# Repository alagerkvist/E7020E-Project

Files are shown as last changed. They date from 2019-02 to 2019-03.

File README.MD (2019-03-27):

# Embbeded Audio Effects

E7020E Embedded System Design is a course giving at Lulea University of Technology. [Link to course syllabus](https://www.ltu.se/edu/course/E70/E7020E/E7020E-Design-av-inbyggda-system-1.67927?kursView=kursplan&l=en)

The purpose of this course is to get a understanding of embedded system and applying that knowledge into designing your own system. Our group did a system that can manipulate audio (adding effects). Where giving an audio input, add some effects and then output it on a speaker.

## Getting Started

* Start by installing Rust for embedded system, follow [this](https://rust-embedded.github.io/book/intro/install.html) guide. 
* Install OpenOCD (version 0.10.0)
* Install arm-none-eabi-gdb (version 8.2.1)
* We are using as of 2019-03-27: rustc 1.34.0-nightly (8a57831a4 2019-02-02)

### Building software
* Clone the repo ``` git clone https://github.com/alagerkvist/E7020E-Project.git ```
* If you would like to use the latest main program run ``` cargo build --release ```
* For examples, run ``` cargo build --example NAME_OF_RS_FILE (codec) ```

## Deployment

* Create FIFO file ``` mkfifo /tmp/itm.log ```
* Start your ITM trace ``` itmdump -f /tmp/itm.log -F ```
* Start OpenOCD ``` openocd -f openocd.cfg ```
* Start gdb ``` arm-none-eabi-gdb target/thumbv7em-none-eabinhf/debug/examples/NAME_OF_RS_FILE -x openocd.gdb ```

## Authors

* **Christoffer Forsberg** - *PCB design*
* **Anders Lagerkvist** - *Programming*
* **Gustav Larsson** - *Programming* 

## Grades
**3**
* Control lamp with PWM signal through UART/potentiometer/button

* **Christoffer Forsberg** - *PWM signal*
* **Anders Lagerkvist** - *ADC for potentiometer*
* **Gustav Larsson** - *Button and UART*

**4**
* Store input siganl in RAM with the help of a button
* Get a sinus wave to output to the codec
* Do an echo with the "signal"
* Show settings on LCD
* Implement I2S/(I2C/SPI) for audio codec

* **Christoffer Forsberg** - *Signal processing, store audio input to RAM with button*
* **Anders Lagerkvist** - *LCD, I2S sine wave output to codec*
* **Gustav Larsson** - *LCD I2C/SPI*

**5**
* Overlay two signals as output
* Integrate different impulse for signal proccessing
* Use an USB as storage

* **Christoffer Forsberg** - *Real time signal processing*
* **Anders Lagerkvist** - *USB implementation*
* **Gustav Larsson** - *Real time signal processing*

## Implemented features

* PWM/LED
* Button
* LCD
* Codec (ish)
* ADC

## Known issues and limitation

* MCUs adc can only read from one potentiometer
* LCD screen has no library yet, so it's a pain in the a** to write to it
* As of now, the codec is inconsistent when writing to it, possible reason to this can be impedance mismatch or wrongfully clock generation 
* PCB layout for 5V to 3.3V regulator is not right implemented
* Footprint for mini-usb type B is placed wrong, should be the other way around (no possibility to mount it on the PCB as of now)
* Codec is in master mode, and should be in slave mode (can be fixed with a pull down resistor instead of a pull up resistor)
* Layout for the potentiometer is too close, needs to seperate more
* Footprint for RCA connector needs to be bigger in their NPTH hole 

## Future work

* Implement ADC so it can be read from three potentiometers
* Library for LCD
* Successfully send data to codec
* Store data from codec into ram
* Sound processing (filter or convolution implementation)
* Store/read data on USB 

## Acknowledgments
PhD Student Cristina Paniagua [Link to profile](https://www.ltu.se/staff/c/cripan-1.167417?l=en)

Professor Per Lindgren [Link to profile](https://www.ltu.se/staff/p/pln-1.11258?l=en)

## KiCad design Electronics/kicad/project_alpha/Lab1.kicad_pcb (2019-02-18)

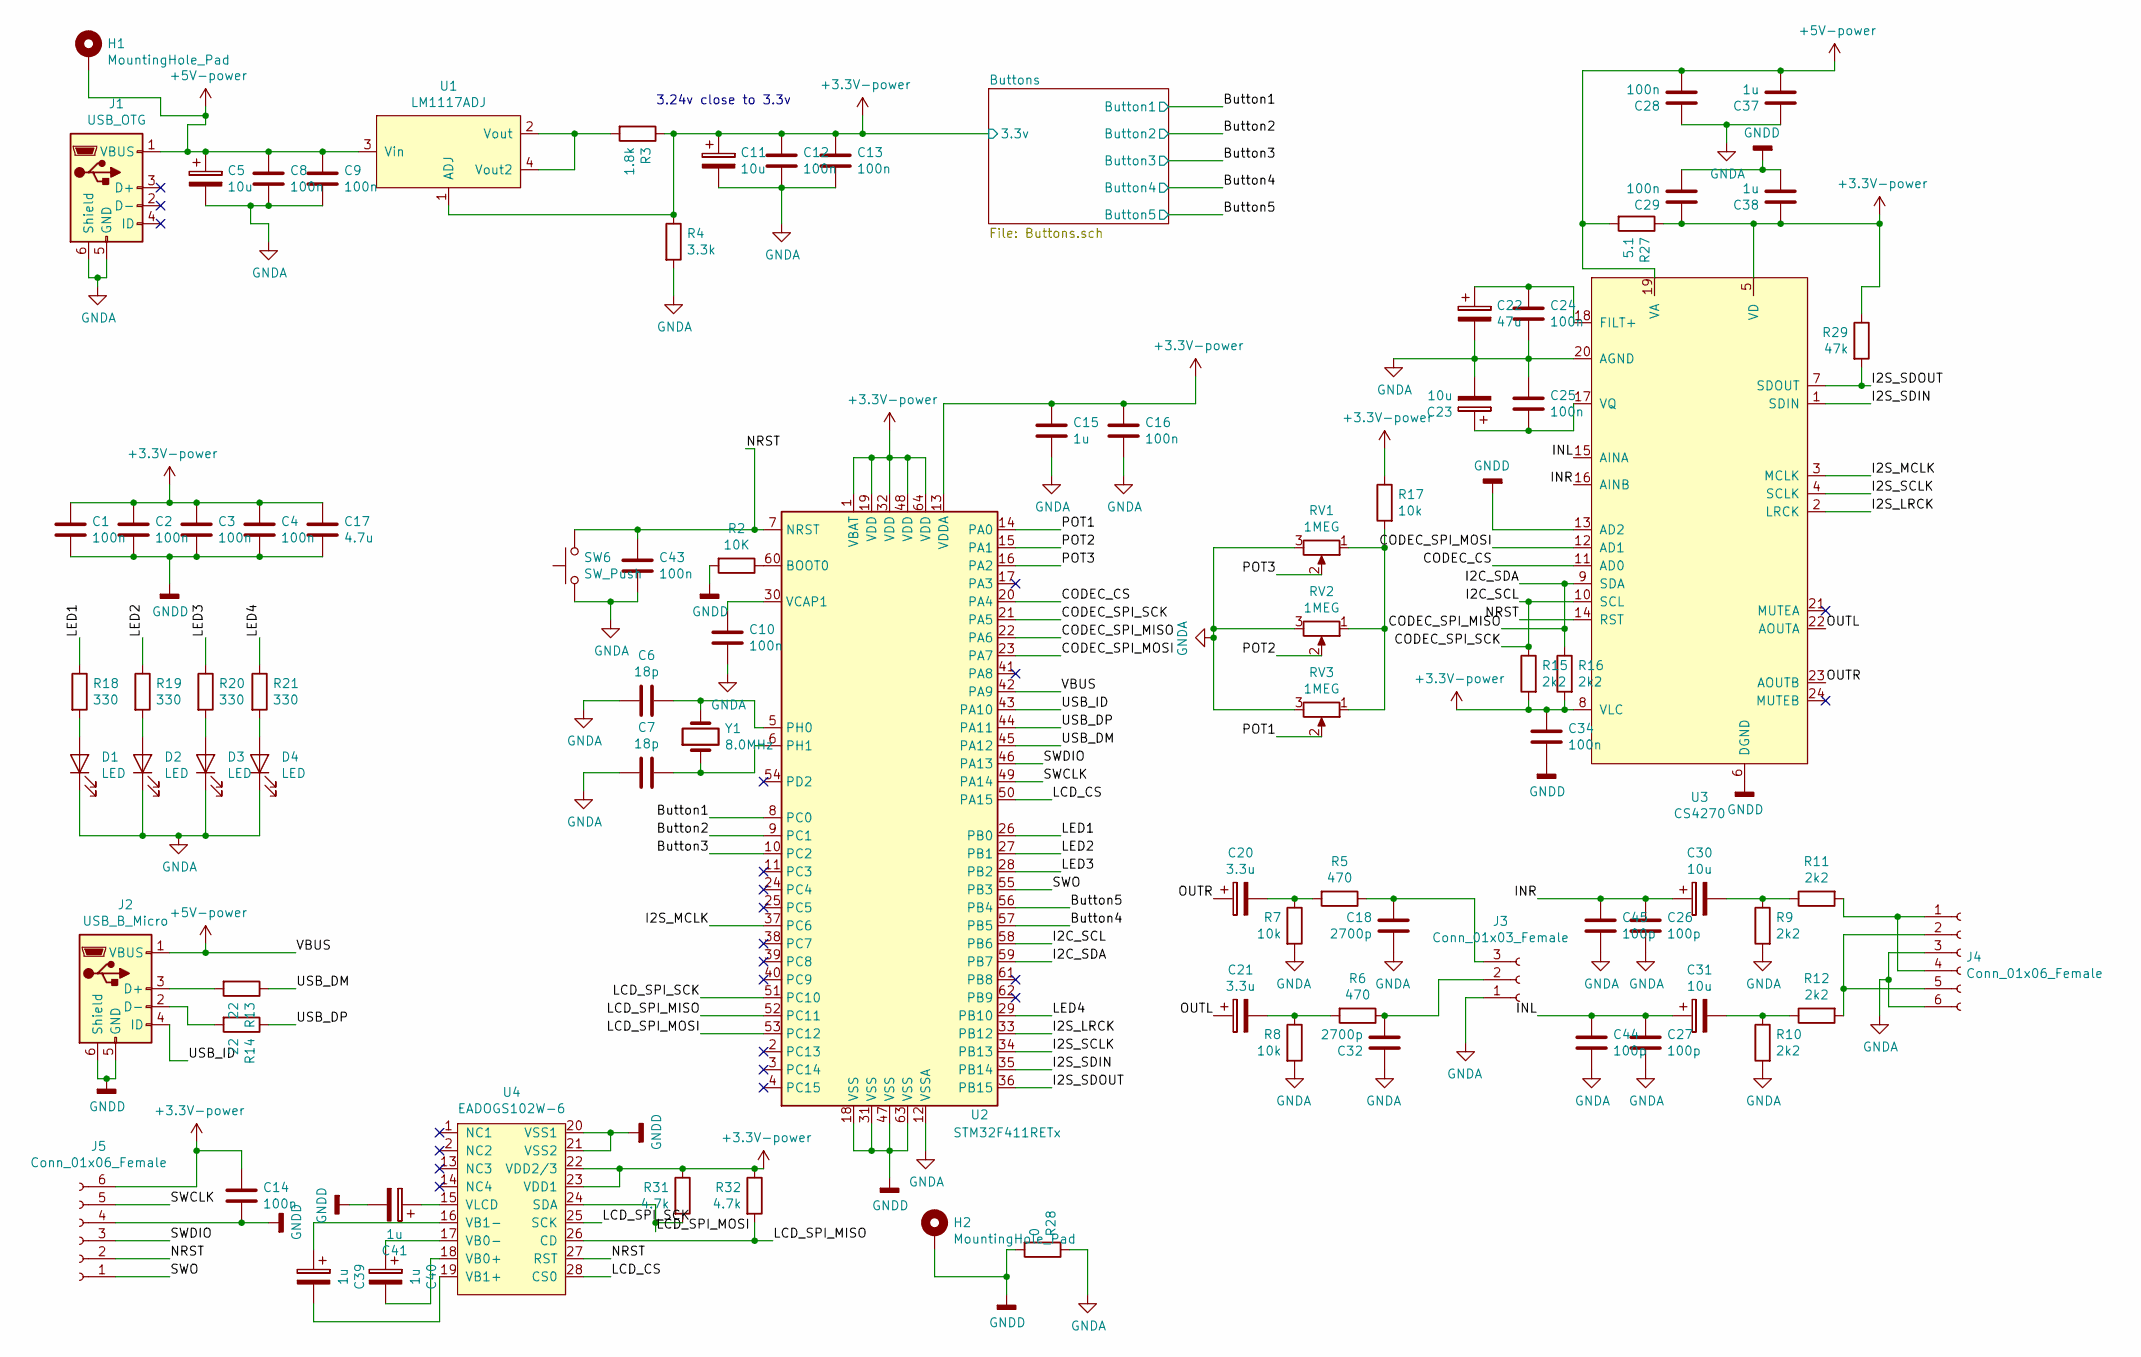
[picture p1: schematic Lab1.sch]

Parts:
C1, C2, C3, C4, C8, C9, C10, C12, C13, C14, C16, C24, C25, C28, C29, C34, C43: 100n; C_0805_2012Metric_Pad1.15x1.40mm_HandSolder
C5: 10u; CP_Elec_4x5.4
C6, C7: 18p; C_0805_2012Metric_Pad1.15x1.40mm_HandSolder
C11: 10u; CP_Elec_5x5.9
C15, C37, C38: 1u; C_0805_2012Metric_Pad1.15x1.40mm_HandSolder
C17: 4.7u; C_0805_2012Metric_Pad1.15x1.40mm_HandSolder
C18, C32: 2700p; C_0805_2012Metric_Pad1.15x1.40mm_HandSolder
C20, C21: 3.3u; CP_Elec_4x5.4
C22: 47u; CP_Elec_5x5.4
C23, C30, C31: 10u; CP_Elec_4x5.3
C26, C27, C44, C45: 100p; C_0805_2012Metric_Pad1.15x1.40mm_HandSolder
C39, C40, C41: 1u; CP_Elec_4x5.4
D1, D2, D3, D4: LED; LED_D3.0mm
H1, H2: MountingHole_Pad; MountingHole_4.5mm_Pad
J1: USB_OTG; USB_Mini-B_AdamTech_MUSB-B5-S-VT-TSMT-1_SMD_Vertical
J2: USB_B_Micro; USB_A_remade
J3: Conn_01x03_Female; RCA
J4: Conn_01x06_Female; 6.35_stero_jack_socket
J5: Conn_01x06_Female; Molex_KK-254_AE-6410-06A_1x06_P2.54mm_Vertical
R2: 10K; R_0805_2012Metric_Pad1.15x1.40mm_HandSolder
R3: 1.8k; R_0805_2012Metric_Pad1.15x1.40mm_HandSolder
R4: 3.3k; R_0805_2012Metric_Pad1.15x1.40mm_HandSolder
R5, R6: 470; R_0805_2012Metric_Pad1.15x1.40mm_HandSolder
R7, R8, R17: 10k; R_0805_2012Metric_Pad1.15x1.40mm_HandSolder
R9, R10, R11, R12, R15, R16: 2k2; R_0805_2012Metric_Pad1.15x1.40mm_HandSolder
R13, R14: 22; R_0805_2012Metric_Pad1.15x1.40mm_HandSolder
R18, R19, R20, R21: 330; R_0805_2012Metric_Pad1.15x1.40mm_HandSolder
R27: 5.1; R_0805_2012Metric_Pad1.15x1.40mm_HandSolder
R28: 0; R_0805_2012Metric_Pad1.15x1.40mm_HandSolder
R29: 47k; R_0805_2012Metric_Pad1.15x1.40mm_HandSolder
R31, R32: 4.7k; R_0805_2012Metric_Pad1.15x1.40mm_HandSolder
RV1, RV2, RV3: 1MEG; rotary_pot
SW6: SW_Push; SW_SPST_B3S-1000
U1: LM1117ADJ; SOT-223
U2: STM32F411RETx; LQFP-64_10x10mm_P0.5mm
U3: CS4270
U4: EADOGS102W-6; EA-DOGS102W-6
Y1: 8.0MHz; Crystal_SMD_HC49-SD

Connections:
+3V3: C1.1, C2.1, C3.1, C4.1, C11.1, C12.1, C13.1, C14.1, C15.1, C16.1, C17.1, C29.1, C34.1, C38.1, J5.6, R3.1, R4.1, R15.2, R16.2, R17.1, R27.1, R29.1, R31.1, R32.1, U1.1 (ADJ), U2.1 (VBAT), U2.13 (VDDA), U2.19 (VDD), U2.32 (VDD), U2.48 (VDD), U2.64 (VDD), U3.5 (VD), U3.8 (VLC), U4.22 (VDD2/3), U4.23 (VDD1); also elsewhere on the board
+5V: C5.1, C8.1, C9.1, C28.2, C37.2, H1.1, J1.1 (VBUS), J2.1 (VBUS), R27.2, U1.3 (Vin), U2.42 (PA9), U3.19 (VA)
/Button1: U2.8 (PC0); also elsewhere on the board
/Button2: U2.9 (PC1); also elsewhere on the board
/Button3: U2.10 (PC2); also elsewhere on the board
/Button4: U2.57 (PB5); also elsewhere on the board
/Button5: U2.56 (PB4); also elsewhere on the board
/CODEC_CS: U2.20 (PA4), U3.11 (AD0)
/CODEC_SPI_MOSI: U2.23 (PA7), U3.12 (AD1)
/I2S_LRCK: U2.33 (PB12), U3.2 (LRCK)
/I2S_MCLK: U2.37 (PC6), U3.3 (MCLK)
/I2S_SCLK: U2.34 (PB13), U3.4 (SCLK)
/I2S_SDIN: U2.35 (PB14), U3.1 (SDIN)
/I2S_SDOUT: R29.2, U2.36 (PB15), U3.7 (SDOUT)
/INL: C27.1, C31.1, C44.1, U3.15 (AINA)
/INR: C26.1, C30.1, C45.1, U3.16 (AINB)
/LCD_CS: U2.50 (PA15), U4.28 (CS0)
/LCD_SPI_MISO: R32.2, U2.52 (PC11), U4.26 (CD)
/LCD_SPI_MOSI: R31.2, U2.53 (PC12), U4.24 (SDA)
/LCD_SPI_SCK: U2.51 (PC10), U4.25 (SCK)
/LED1: R18.1, U2.26 (PB0)
/LED2: R19.1, U2.27 (PB1)
/LED3: R20.1, U2.28 (PB2)
/LED4: R21.1, U2.29 (PB10)
/NRST: C43.1, J5.2, SW6.2, U2.7 (NRST), U3.14 (RST), U4.27 (RST)
/OUTL: C21.1, U3.22 (AOUTA)
/OUTR: C20.1, U3.23 (AOUTB)
/POT1: RV3.2, U2.14 (PA0)
/POT2: RV2.2, U2.15 (PA1)
/POT3: RV1.2, U2.16 (PA2)
/SWCLK: J5.5, U2.49 (PA14)
/SWDIO: J5.3, U2.46 (PA13)
/SWO: J5.1, U2.55 (PB3)
/USB_DM: R13.1, U2.45 (PA12)
/USB_DP: R14.1, U2.44 (PA11)
/USB_ID: J2.4 (ID), U2.43 (PA10)
GNDA: C5.2, C6.1, C7.1, C8.2, C9.2, C10.2, C11.2, C12.2, C13.2, C15.2, C16.2, C18.2, C22.2, C23.2, C24.2, C25.1, C26.2, C27.2, C28.1, C32.1, C37.1, C43.2, C44.2, C45.2, D1.1 (K), D2.1 (K), D3.1 (K), D4.1 (K), J1.5 (GND), J1.6 (Shield), J3.1, J4.3, J4.6, R4.2, R7.2, R8.2, R9.2, R10.2, R28.1, RV1.3, RV2.3, RV3.3, SW6.1, U2.12 (VSSA), U3.20 (AGND); also elsewhere on the board
GNDD: C1.2, C2.2, C3.2, C4.2, C14.2, C17.2, C29.2, C34.2, C38.2, C41.2, H2.1, J2.5 (GND), J2.6 (Shield), J5.4, R2.2, R28.2, U2.18 (VSS), U2.31 (VSS), U2.47 (VSS), U2.63 (VSS), U3.6 (DGND), U3.13 (AD2), U4.20 (VSS1), U4.21 (VSS2); also elsewhere on the board
unnamed: C6.2, U2.5 (PH0), Y1.2
unnamed: C7.2, U2.6 (PH1), Y1.1
unnamed: C10.1, U2.30 (VCAP1)
unnamed: C18.1, J3.3, R5.1
unnamed: C20.2, R5.2, R7.1
unnamed: C21.2, R6.2, R8.1
unnamed: C22.1, C24.1, U3.18 (FILT+)
unnamed: C23.1, C25.2, U3.17 (VQ)
unnamed: C30.2, R9.1, R11.1
unnamed: C31.2, R10.1, R12.1
unnamed: C32.2, J3.2, R6.1
unnamed: C39.1, U4.16 (VB1-)
unnamed: C39.2, U4.19 (VB1+)
unnamed: C40.1, U4.17 (VB0-)
unnamed: C40.2, U4.18 (VB0+)
unnamed: C41.1, U4.15 (VLCD)
unnamed: D1.2 (A), R18.2
unnamed: D2.2 (A), R19.2
unnamed: D3.2 (A), R20.2
unnamed: D4.2 (A), R21.2
unnamed: J2.2 (D-), R14.2
unnamed: J2.3 (D+), R13.2
unnamed: J4.1, J4.4, R11.2
unnamed: J4.2, J4.5, R12.2
unnamed: R2.1, U2.60 (BOOT0)
unnamed: R3.2, U1.2 (Vout), U1.4 (Vout2)
unnamed: R17.2, RV1.1, RV2.1, RV3.1

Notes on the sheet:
3.24v close to 3.3v

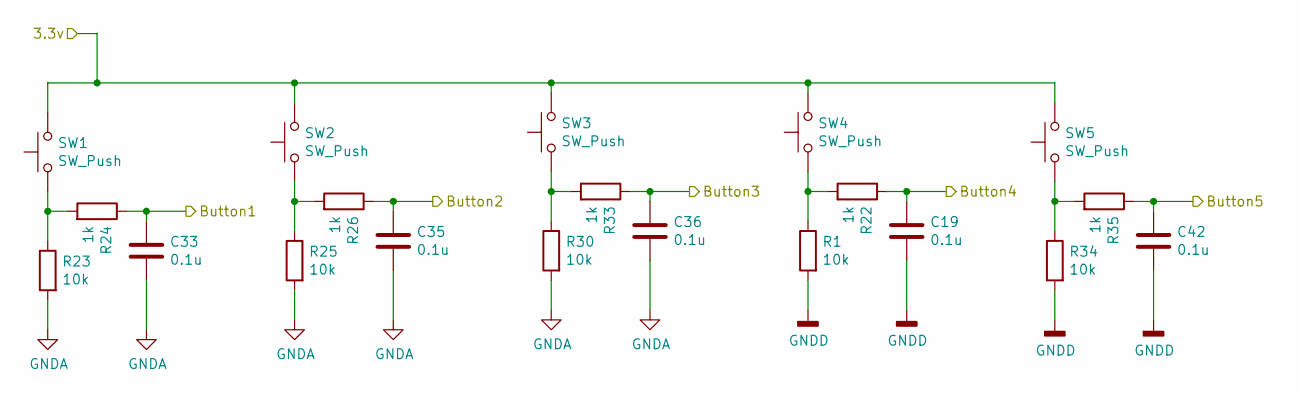
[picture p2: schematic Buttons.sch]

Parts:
C19, C33, C35, C36, C42: 0.1u; C_0805_2012Metric_Pad1.15x1.40mm_HandSolder
R1, R23, R25, R30, R34: 10k; R_0805_2012Metric_Pad1.15x1.40mm_HandSolder
R22, R24, R26, R33, R35: 1k; R_0805_2012Metric_Pad1.15x1.40mm_HandSolder
SW1, SW2, SW3, SW4, SW5: SW_Push; SW_SPST_B3S-1000

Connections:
+3V3: SW1.2, SW2.2, SW3.2, SW4.2, SW5.2; also elsewhere on the board
/Button1: C33.1, R24.1; also elsewhere on the board
/Button2: C35.1, R26.1; also elsewhere on the board
/Button3: C36.1, R33.1; also elsewhere on the board
/Button4: C19.1, R22.1; also elsewhere on the board
/Button5: C42.1, R35.1; also elsewhere on the board
GNDA: C33.2, C35.2, C36.2, R23.2, R25.2, R30.2; also elsewhere on the board
GNDD: C19.2, C42.2, R1.2, R34.2; also elsewhere on the board
unnamed: R1.1, R22.2, SW4.1
unnamed: R23.1, R24.2, SW1.1
unnamed: R25.1, R26.2, SW2.1
unnamed: R30.1, R33.2, SW3.1
unnamed: R34.1, R35.2, SW5.1

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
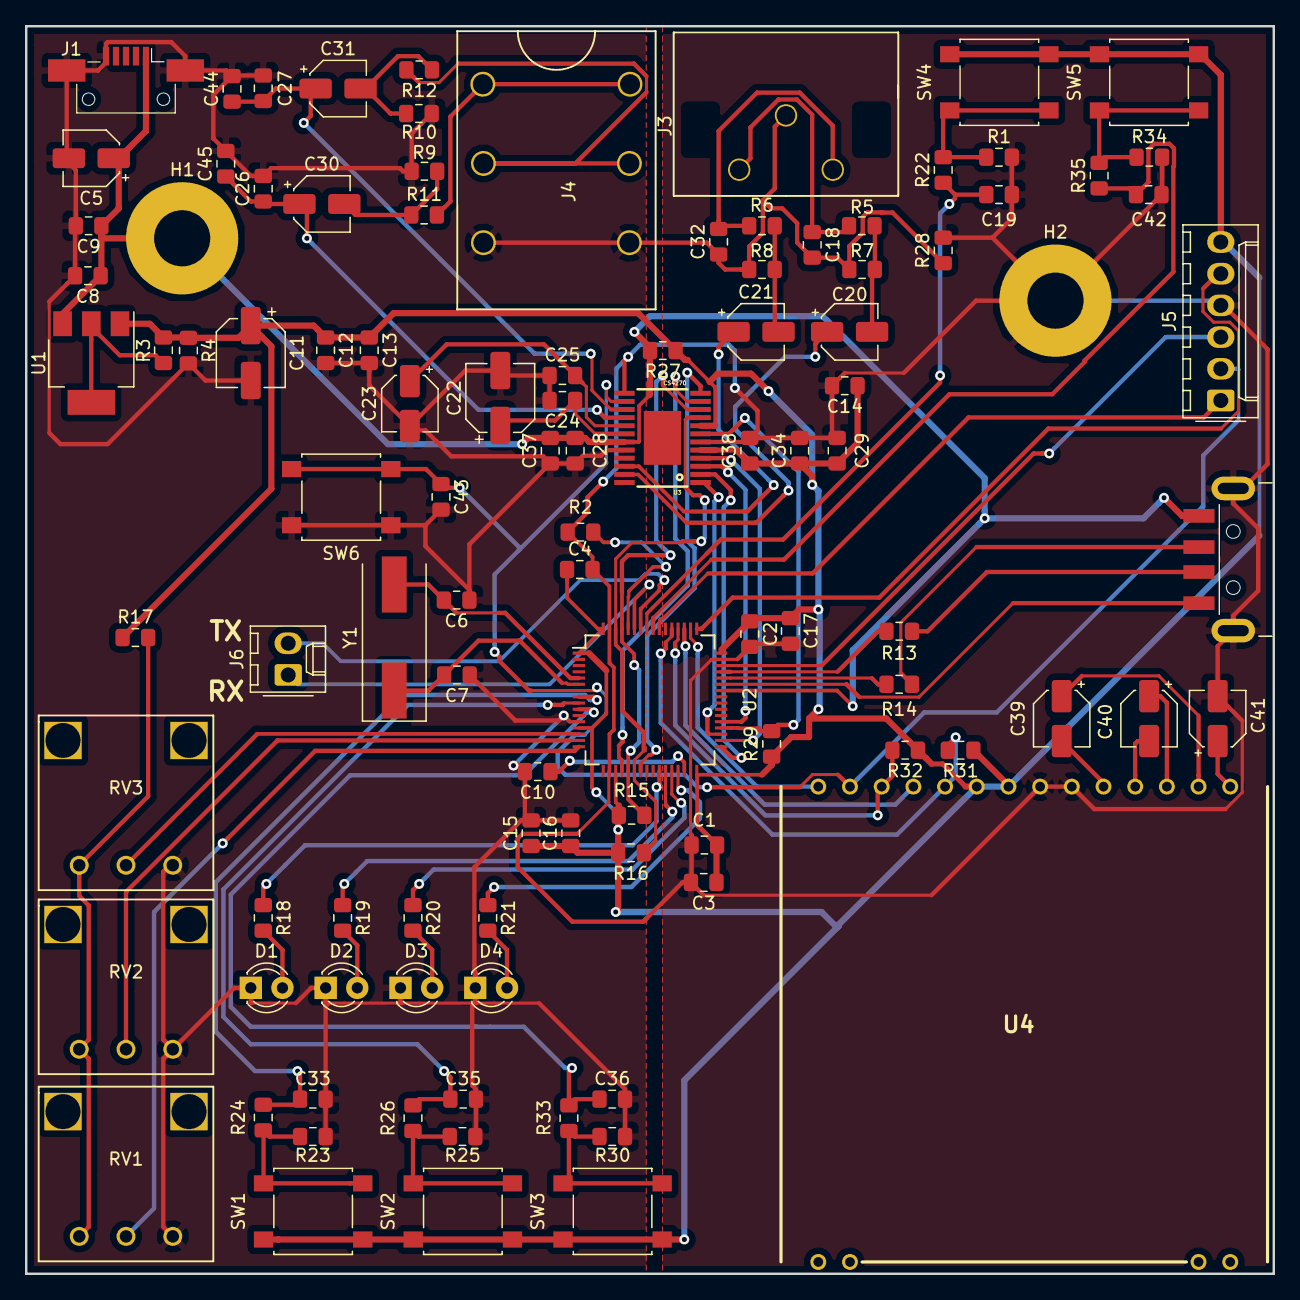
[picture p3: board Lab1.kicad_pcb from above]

Board: 2 copper layers, 100.0 x 100.0 mm, 106 parts (0 on the bottom side), 74 nets.

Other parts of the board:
J6: Conn_01x02_Female; Molex_KK-254_AE-6410-02A_1x02_P2.54mm_Vertical

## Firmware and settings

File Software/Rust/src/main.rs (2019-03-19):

#![no_main]
#![no_std]

extern crate cortex_m;
extern crate panic_halt;
//extern crate stm32f4;
extern crate stm32f4xx_hal as hal;
use crate::hal::prelude::*;
use cortex_m::{asm, iprintln};
use hal::stm32::ITM;
use hal::stm32::ADC1;
use hal::stm32::GPIOB;
use hal::stm32::SPI3;
use hal::spi::{Spi, Mode, Phase, Polarity, NoMiso};
use hal::gpio::{Alternate, AF6, PushPull, Output};
use hal::gpio::gpioc::{PC10, PC11, PC12};
use hal::gpio::gpioa::{PA15};
use rtfm::{app, Instant};
mod lcd;
use lcd::*;
const PERIOD: u32 = 400_000;

#[app(device = hal::stm32)]
const APP: () = {
    static mut GPIOB: GPIOB = ();
    static mut Duty_cycle: f32 = 0.5; // Duty range = [20 80]%
    static mut Pwm_on: u32 = 0;
    static mut Pwm_off: u32 = 0;
    static mut ITM: ITM = ();    
    static mut ADC: ADC1 = ();
    static mut LCD_SCREEN: EA_dogs102_6w<Spi<SPI3, (PC10<Alternate<AF6>>, NoMiso, PC12<Alternate<AF6>>)>, PA15<Output<PushPull>>, PC11<Output<PushPull>>> = ();
    //static mut adc_data: dr<hal::stm32::adc1> = ();
    // init runs in an interrupt free section
    #[init(schedule = [on], resources=[Pwm_on, Pwm_off, Duty_cycle], spawn=[update_pwm])]
    fn init() {
        //let mut c = hal::stm32::CorePeripherals::take().unwrap();
        let stim = &mut core.ITM.stim[0];
       
        device.RCC.ahb1enr.modify(|_, w| w.gpioaen().set_bit()); //Enable GPIOA clock
        device.RCC.apb2enr.modify(|_, w| w.adc1en().set_bit());
        device.RCC.ahb1enr.modify(|_, w| w.gpioben().set_bit());

        device.ADC1.cr2.modify(|_, w| w.adon().clear_bit());
        device.ADC1.cr1.modify(|_, w| w.eocie().set_bit());
        device.ADC1.cr2.modify(|_, w|{
            w.align()
            .clear_bit()
            .cont()
            .clear_bit()
        //    .cont()
        //    .continuous()
        });
        device.ADC1.smpr2.modify(|_, w| w.smpx_x().cycles480());
        device.ADC1.cr2.modify(|_, w| w.adon().set_bit());
        device.ADC1.sqr3.modify(|_, w| unsafe { w.sq1().bits(0 as u8) });
        //device.ADC1.sqr3.modify(|_, w| unsafe { w.sq2().bits(2 as u8) });
        
        device.ADC1.sqr1.modify(|_,w| w.l().bits(0));
        let gpioa = device.GPIOA.split();
        gpioa.pa0.into_analog();
        //gpioa.pa2.into_analog();
        
        let rcc = device.RCC.constrain();

        // 16 MHz (default, all clocks)
        let clocks = rcc.cfgr.freeze();
        let gpioc = device.GPIOC.split();
        let sck = gpioc.pc10.into_alternate_af6();
        let mosi = gpioc.pc12.into_alternate_af6();
        
        let mut cd = gpioc.pc11.into_push_pull_output();
        let mut cs = gpioa.pa15.into_push_pull_output();

        pub const MODE: Mode = Mode {
            polarity: Polarity::IdleHigh,
            phase: Phase::CaptureOnFirstTransition,
        };
        let mut spi = Spi::spi3(
            device.SPI3,
            (sck, NoMiso, mosi),
            MODE,
            10_000_000.hz(),
            clocks
        );

        let mut lcd1 = EA_dogs102_6w::init(spi, cs, cd).unwrap();
        lcd1.write_word("Duty cycle: ");
        
        //lcd1.init();
        
        iprintln!(stim, "main");
        //device.ADC1.cr2.modify(|_, w| w);
        device.ADC1.cr2.modify(|_, w| w.swstart().set_bit());
        //*resources.Pwm_on = (PERIOD as f32 * *resources.Duty_cycle) as u32;
        //*resources.Pwm_off = PERIOD - *resources.Pwm_on;
        spawn.update_pwm(*resources.Duty_cycle);
        //schedule.foo(Instant::now() + PERIOD.cycles()).unwrap();
        // configure PA5 as output, RM0368 8.4.1
        device.GPIOB.moder.modify(|_, w| w.moder1().bits(1));

        // pass on late resources

        schedule.on(Instant::now());
        GPIOB = device.GPIOB;
        ADC = device.ADC1;
        ITM = core.ITM;
        LCD_SCREEN = lcd1;

    }

    #[idle]
    fn idle() -> ! {
        loop {
            asm::wfi();
        }
    }

    #[task(priority = 3, schedule = [off], resources=[Pwm_on, GPIOB])]
    fn on() {
        resources.GPIOB.bsrr.write(|w| w.bs1().set_bit());
        let a = *resources.Pwm_on;
        schedule.off(scheduled + a.cycles()).unwrap();
    }

    #[task(priority = 3, schedule = [on], resources=[Pwm_off, GPIOB])]
    fn off() {
        resources.GPIOB.bsrr.write(|w| w.br1().set_bit());
        let a = *resources.Pwm_off;
        schedule.on(scheduled + a.cycles()).unwrap();
    }

    #[task(priority = 3, resources = [Pwm_on, Pwm_off, Duty_cycle])]
    fn update_pwm(dc: f32){
        let mut pwm: u32 = 0;
        resources.Pwm_on.lock(|pwm_on|{
            *pwm_on = (PERIOD as f32 * dc) as u32;
            pwm = *pwm_on;
        });
        resources.Pwm_off.lock(|pwm_off|{
            *pwm_off = PERIOD - pwm;
        });
        *resources.Duty_cycle = dc;
    }

    #[task(priority = 3, resources = [ITM, LCD_SCREEN], spawn = [update_pwm])]
    fn change_freq(val: u32) {
        let duty_cycle_percent: f32 = ((val as f32) * (80.0-20.0) / (4050.0) + 20.0);
        spawn.update_pwm(duty_cycle_percent / 100.0);
        let stim = &mut resources.ITM.stim[0];
        resources.LCD_SCREEN.update_duty(duty_cycle_percent as u32);
        iprintln!(stim, "val: {}", duty_cycle_percent);
    }

    #[task(priority = 1, resources = [ADC])]
    fn restart_adc(){
        resources.ADC.lock(|adc|{
            adc.sr.modify(|_, w| w.eoc().clear_bit());
            adc.sr.modify(|_, w| w.ovr().clear_bit());
            adc.cr2.modify(|_, w| w.swstart().set_bit()); 
        });
    }

    #[interrupt(priority = 3, resources = [ADC], spawn = [change_freq,restart_adc], schedule=[restart_adc])]
    fn ADC() {
        let value: u32 = resources.ADC.dr.read().bits();
        spawn.change_freq(value);
        //resources.ADC.cr2.modify(|_, w| w.swstart().set_bit());         
        spawn.restart_adc();
        //schedule.restart_adc(Instant::now() + 4_000_000.cycles()).unwrap();

    }

    extern "C" {
        fn EXTI0();
        fn EXTI1();
    }

};

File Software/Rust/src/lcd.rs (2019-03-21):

#![no_main]
#![no_std]

extern crate stm32f4xx_hal as hal;
use hal::prelude::_embedded_hal_digital_OutputPin as OutputPin;
use hal::prelude::_embedded_hal_blocking_spi_Write as Write;
use hal::spi::{Spi, Mode, Phase, Polarity, NoMiso};


#[derive(Debug)]
pub enum Error<E> {
    Spi(E),
}

enum Command{

}

enum Letter{
    Space,
    Percent,
    Zero,
    One,
    Two,
    Three,
    Four,
    Five,
    Six,
    Seven,
    Eight,
    Nine,
    Colon,
    D,
    c,
    e,
    l,
    t,
    u,
    y,
}

impl Letter {
    fn value(&self) -> &[u8] {
        match *self {
            Letter::Space => &[0,0,0,0,0,0],
            Letter::Percent => &[35, 19, 8, 100, 98, 0],
            Letter::Zero => &[62, 81, 73, 69, 62,  0],
            Letter::One => &[0, 66,127, 64,  0,  0],
            Letter::Two => &[66, 97, 81, 73, 70,  0],
            Letter::Three => &[33, 65, 73, 77, 51,  0],
            Letter::Four => &[24, 20, 18,127, 16,  0],
            Letter::Five => &[39, 69, 69, 69, 57,  0],
            Letter::Six => &[60, 74, 73, 73, 48,  0],
            Letter::Seven => &[65, 33, 17,  9,  7,  0],
            Letter::Eight => &[54, 73, 73, 73, 54,  0],
            Letter::Nine => &[6, 73, 73, 41, 30,  0],
            Letter::Colon => &[0,  0, 40,  0,  0,  0],
            Letter::D => &[127, 65, 65, 65, 62,  0],
            Letter::c => &[56, 68, 68, 68, 40,  0],
            Letter::e => &[56, 84, 84, 84, 24,  0],
            Letter::l => &[0, 65,127, 64,  0,  0,],
            Letter::t => &[4, 4, 63, 68, 36, 0],
            Letter::u => &[60, 64, 64, 32, 124, 0],
            Letter::y => &[76, 144, 144, 144, 124, 0],
        }
    }
}
/*
pub struct EA_dogs102_6w<SPI, CS, CD, RESET> {
    spi: SPI,
    cs: CS,
    cd: CD,
    reset: RESET,
}
*/
pub struct EA_dogs102_6w<SPI, CS, CD> {
    spi: SPI,
    cs: CS,
    cd: CD,
}


impl<E, SPI, CS, CD> EA_dogs102_6w<SPI, CS, CD>
where
    SPI: Write<u8, Error = E>,
    CS: OutputPin,
    CD: OutputPin,
{
    pub fn init(
        spi: SPI,
        cs: CS,
        cd: CD,
    ) -> Result<Self, Error<E>> {
        let mut ea_dogs = EA_dogs102_6w {
            spi,
            cs,
            cd,
        };
        ea_dogs.cd.set_low();
        ea_dogs.cs.set_high();
        ea_dogs.cs.set_low();
        ea_dogs.spi.write(&[0x40, 0xA1, 0xC0, 0xA4, 0xA6, 0xA2, 0x2F, 0x27, 0x81, 0x10, 0xFA, 0x90, 0xAF]);
        ea_dogs.cs.set_high();
        ea_dogs.clear_screen();
        Ok(ea_dogs)
    }

    pub fn update_duty(&mut self, duty: u32){
        self.cs.set_low();
        self.cd.set_low();
        let msb_adress = 0x10 + (0x42>>4);
        let lsb_adress = 0x00 + (0x42&0x0F);
        let adress_page = 0xB0 + (0&0x0F);
        self.spi.write(&[msb_adress, lsb_adress, adress_page]);
        self.cd.set_high();
        self.spi.write(Letter::Space.value());
        self.spi.write(Letter::Space.value());
        self.cd.set_low();
        let msb_adress = 0x10 + (0x42>>4);
        let lsb_adress = 0x00 + (0x42&0x0F);
        let adress_page = 0xB0 + (0&0x0F);
        self.spi.write(&[msb_adress, lsb_adress, adress_page]);
        self.cd.set_high();
        self.spi.write(Letter::Zero.value());
    }

    pub fn write_word(&mut self, s: &str){
        self.cd.set_low();
        self.cs.set_low();
        let msb_adress = 0x10 + (0x00>>4); //0x42 set colum address
        let lsb_adress = 0x00 + (0x00&0x0F); //Same but with the lowest bits
        let adress_page = 0xB0 + (0&0x0F);
        self.spi.write(&[msb_adress, lsb_adress, adress_page]);
        self.cd.set_high();
        for (_,letter) in s.chars().enumerate(){
            match letter {
                ' ' => { self.spi.write(Letter::Space.value()); },
                '%' => { self.spi.write(Letter::Percent.value()); }
                ':' => { self.spi.write(Letter::Colon.value()); },
                '0' => { self.spi.write(Letter::Zero.value()); },
                '1' => { self.spi.write(Letter::One.value()); },
                '2' => { self.spi.write(Letter::Two.value()); },
                '3' => { self.spi.write(Letter::Three.value()); },
                '4' => { self.spi.write(Letter::Four.value()); },
                '5' => { self.spi.write(Letter::Five.value()); },
                '6' => { self.spi.write(Letter::Six.value()); },
                '7' => { self.spi.write(Letter::Seven.value()); },
                '8' => { self.spi.write(Letter::Eight.value()); },
                '9' => { self.spi.write(Letter::Nine.value()); },
                'D' => { self.spi.write(Letter::D.value()); },
                'u' => { self.spi.write(Letter::u.value()); },
                't' => { self.spi.write(Letter::t.value()); },
                'y' => { self.spi.write(Letter::y.value()); },
                'c' => { self.spi.write(Letter::c.value()); },
                'l' => { self.spi.write(Letter::l.value()); },
                'e' => { self.spi.write(Letter::e.value()); },
                _  => {},
            };
        }
        self.cs.set_high();
    }

    pub fn clear_screen(&mut self){
        for page in 0..8 {
            //asm::bkpt();
            self.cs.set_low();
            self.cd.set_low();
            let msb_adress = 0x10 + (0>>4);
            let lsb_adress = 0x00 + (0&0x0F);
            let adress_page = 0xB0 + (page&0x0F);
            self.spi.write(&[msb_adress, lsb_adress, adress_page]);
            self.cd.set_high();
            for _ in 0..102 {
                self.spi.write(&[0x00]);
            } 
        }
    }
}

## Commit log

2019-02-11 init kicad scheme and footprints for project
    [Lab1.kicad_pcb, Lab1.sch]
2019-02-11 added datasheets for components for the project
    [_saved_Lab1.sch]
2019-02-11 begin designing PCB
    [Lab1.sch]
2019-02-12 update PCB, not done yet
    [Lab1.kicad_pcb, Lab1.sch]
2019-02-12 update PCB
    [Lab1.kicad_pcb, Lab1.sch]
2019-02-12 started routing PCB
    [Lab1.kicad_pcb]
2019-02-13 finnished PCB routeing, added gerber files
    [Buttons.sch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]
2019-02-15 updated PCB routeing and gerber files
    [Lab1-B.Cu.gbr, Lab1-B.Mask.gbr, Lab1-Edge.Cuts.gbr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]
2019-03-12 pot is working with adc
    [_saved_Buttons.sch, _saved_Lab1.sch]
2019-03-12 added exampel for pwm signal using rtfm
2019-03-14 lcd can print text and pic now
2019-03-19 some fixes with lcd
    [lcd.rs, main.rs]
2019-03-19 LCD should print duty cycle now (not tested)
2019-03-22 iprintln not working now
    [codec.rs]
2019-03-27 added example on how to getstore data from codec. not working at the moment.
    [Codec_RAM.rs, codec.rs]
2019-03-27 updated Codec_RAM.rs, sill not working. Slice Error.
    [Codec_RAM.rs, codec.rs]
2019-03-27 updated Codec_RAM, error is noe fixed. not Tested if functional
    [Codec_RAM.rs]
2019-03-28 Codec_RAM, can save to RAM but not send to codec, buttons do not work, debugging that. added tmp button file for that
    [Codec_RAM.rs]
2019-03-28 updated Codec_RAM, buttons works, bug in writing data to codec, debuging that now
    [Codec_RAM.rs]
2019-05-22 libm with sample is now compiling. not tested on a MCU yet
2019-05-22 sample.rs is an example using a local sample crate compiled with libm
2019-05-22 codec.rs is not working at the moment, working on sample.rs instead (using libm)
    [codec.rs, sample.rs]
